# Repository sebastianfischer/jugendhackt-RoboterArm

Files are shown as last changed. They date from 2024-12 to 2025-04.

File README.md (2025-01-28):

# RoboterArm

Design, Idee und Umsetzung: @dgreiser 

# Was machen wir?
## Step 1: Zusammenbauen
Du baust aus Servomotoren, Gelenken und einem Greifer einen funktionierenden Roboterarm. Keine Sorge, wir erklären alles Schritt für Schritt.

## Step 2: Programmieren
Mit einem Microcontroller (z. B. einem Raspberry Pi Pico) programmierst du, wie der Roboterarm sich bewegen soll. Ob er Sachen greifen, sich drehen oder coole Bewegungen ausführen soll – du steuerst ihn komplett!

# Für wen ist der Workshop?
Für alle zwischen 12 und 18 Jahren, die Lust haben, mit Technik zu experimentieren. Vorkenntnisse? Nicht nötig! Neugier reicht.

# Warum solltest du mitmachen?
- Du lernst, wie Roboter wirklich funktionieren.
- Du tauchst in die Welt der Programmierung ein – ohne langweilige Theorie.
- Du kannst am Ende stolz deinen eigenen Roboterarm präsentieren.
- Es macht einfach mega Spaß, mit anderen zu bauen und zu coden!

# Was brauchst du?
Nichts außer Motivation! Wir stellen alles zur Verfügung, was du für den Workshop brauchst.

See the robot arm in aktion (https://www.youtube.com/watch?v=oafrhNWhoxY)

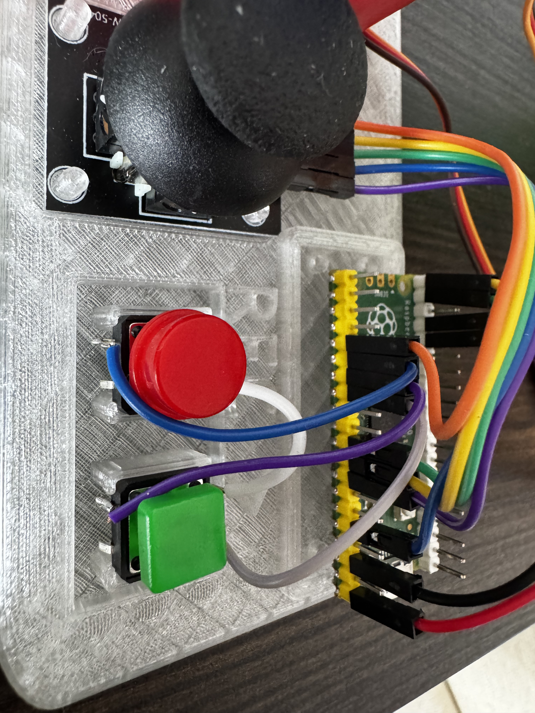
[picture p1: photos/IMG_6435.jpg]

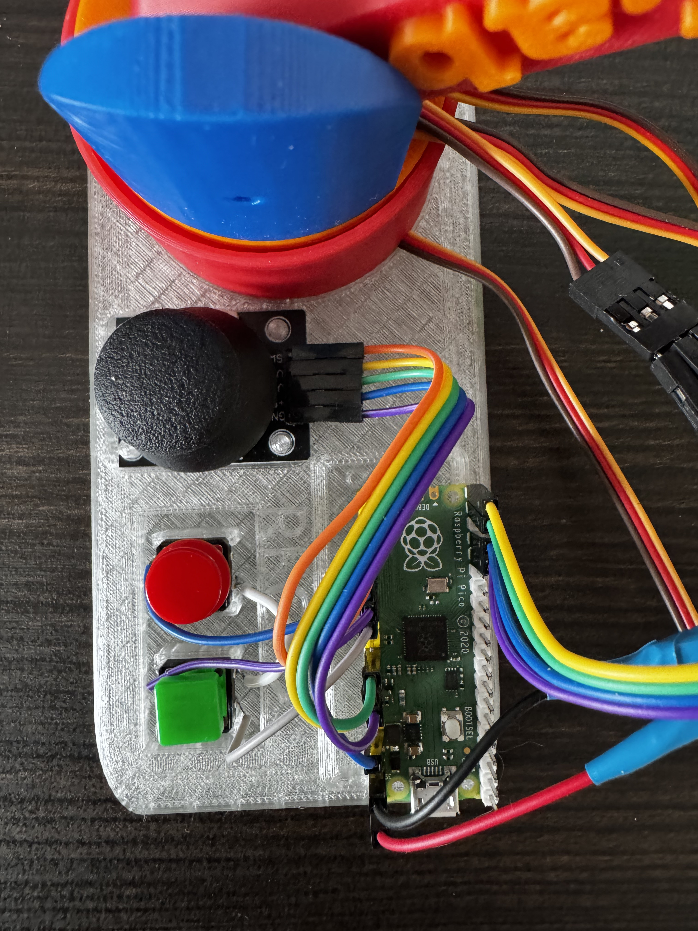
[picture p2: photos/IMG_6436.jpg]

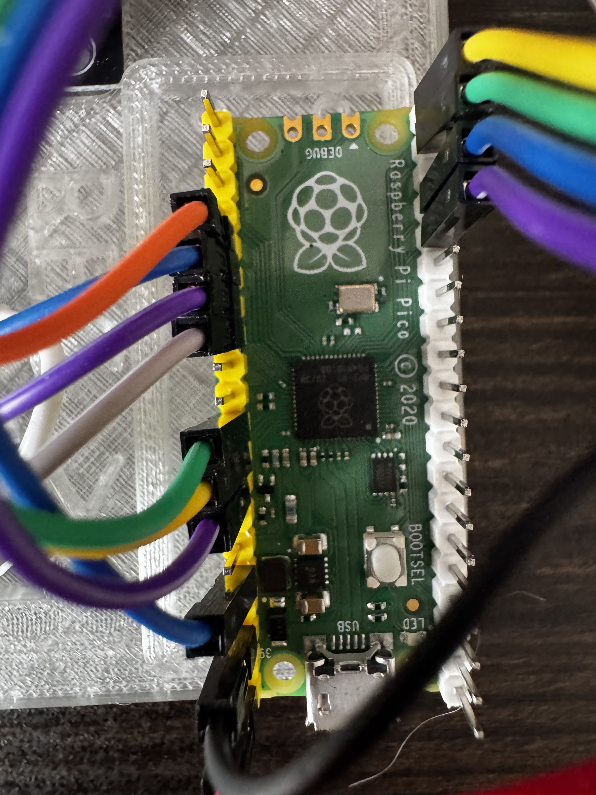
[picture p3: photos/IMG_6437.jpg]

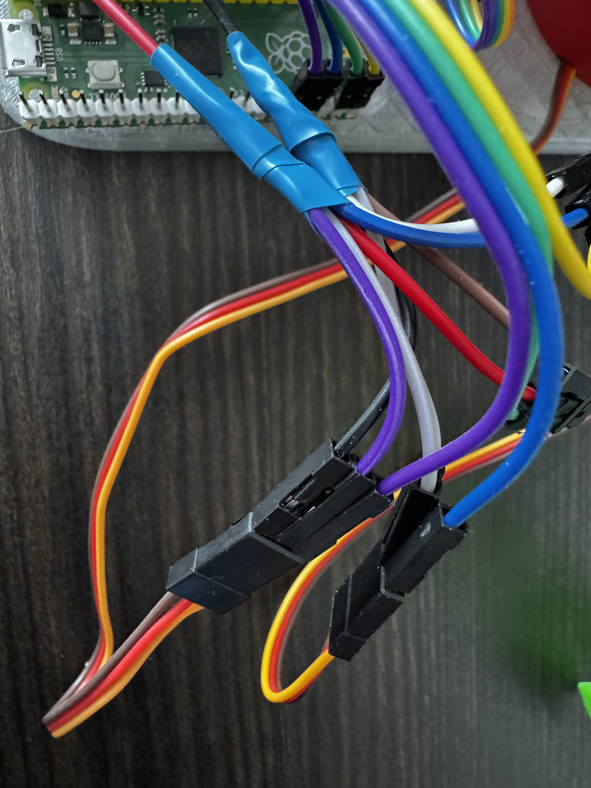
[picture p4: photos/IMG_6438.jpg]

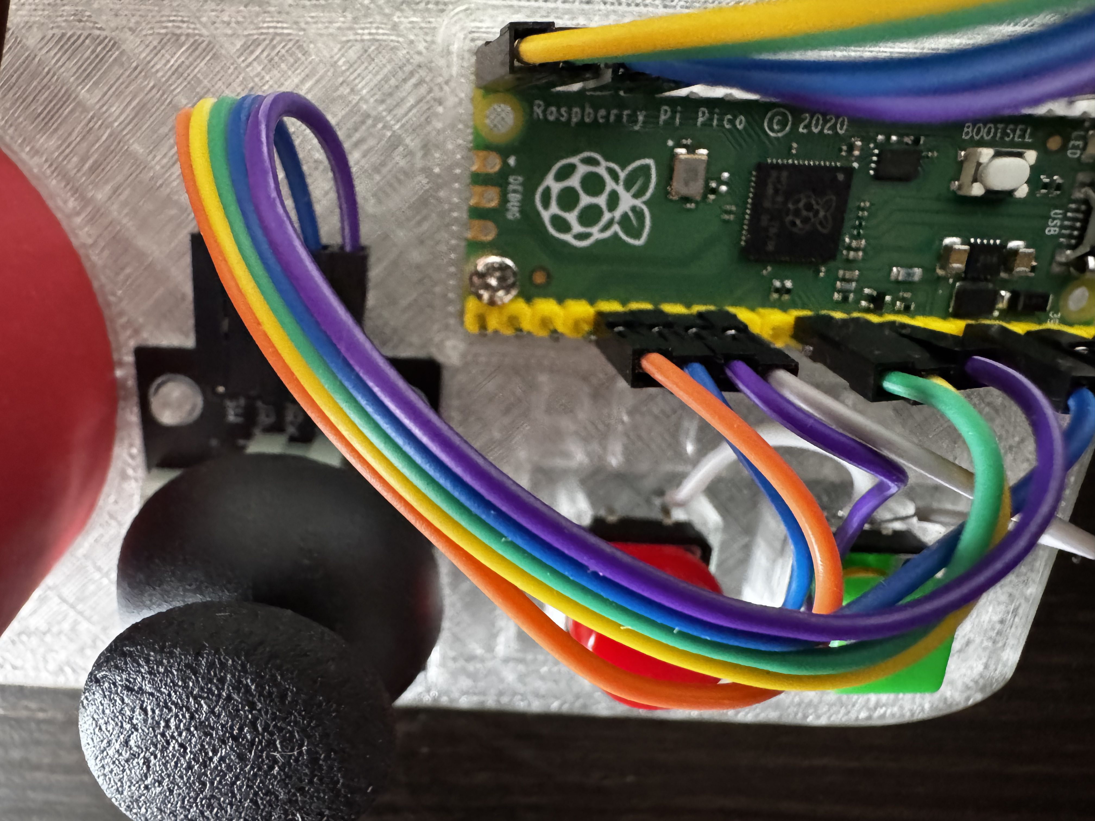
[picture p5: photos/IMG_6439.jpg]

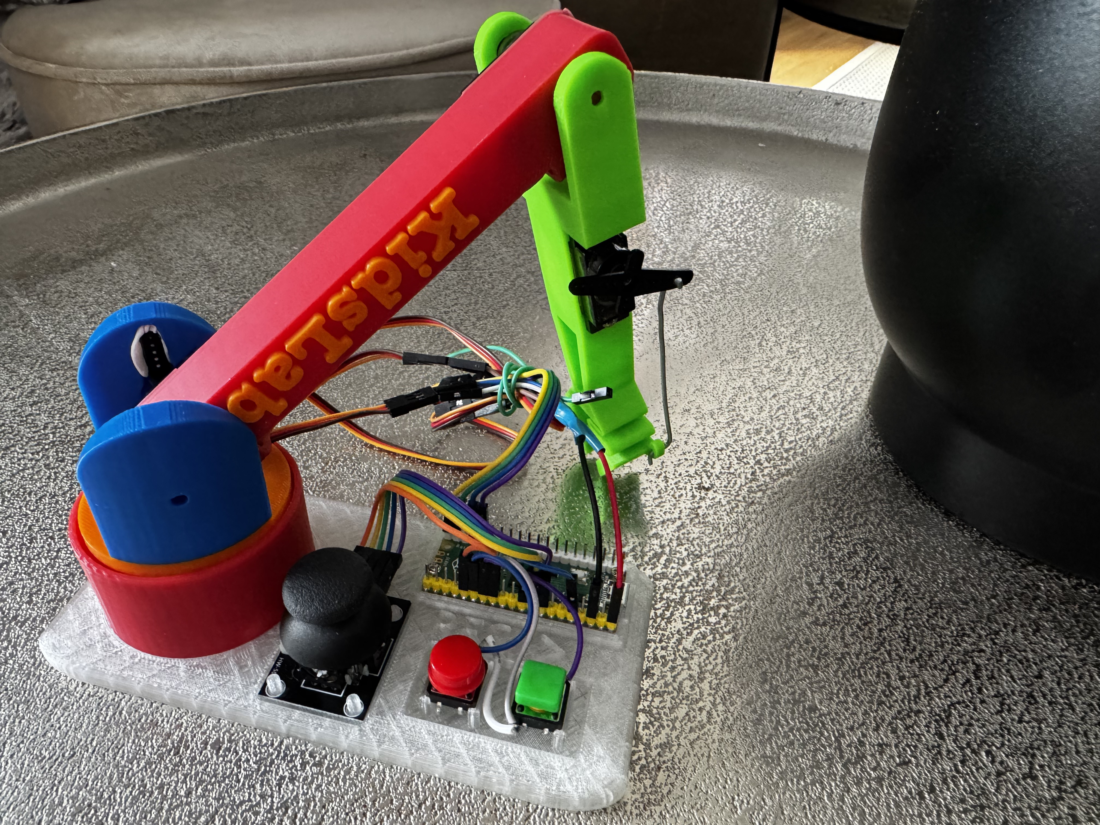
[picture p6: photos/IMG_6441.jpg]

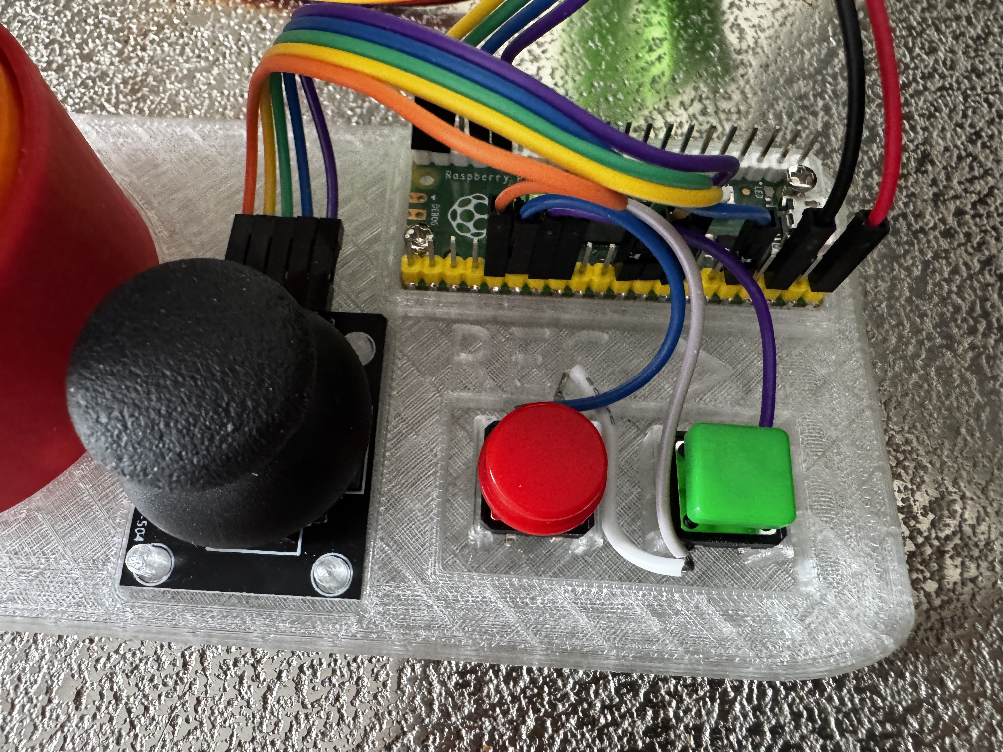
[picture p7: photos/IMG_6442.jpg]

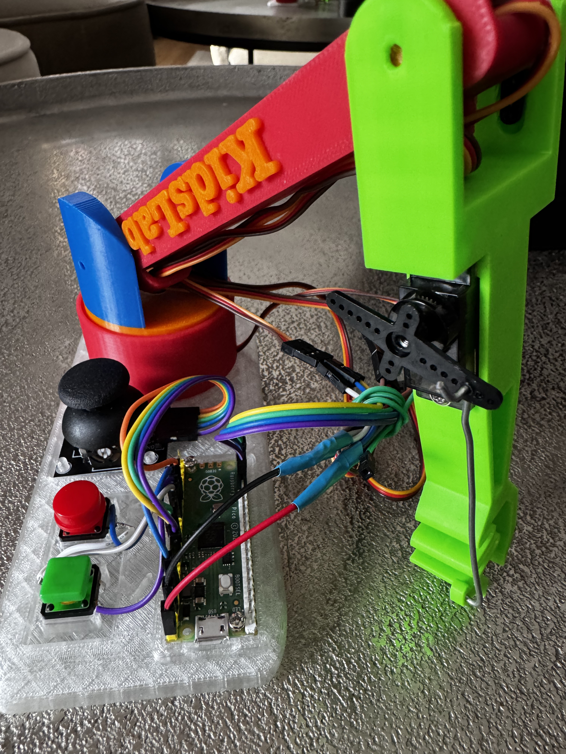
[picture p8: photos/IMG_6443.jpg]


# Teileliste - für den Nachbau zuhause

4x Servos - standard 9g - am besten mit Metalgetriebe
1x Raspberry Pico - oder anderen mit CircuitPython-Unterstützung
1x Joysticj
1x eine Handvoll Kabel 
2x Knöpfe deiner Wahl - zum Beispiel diese hier

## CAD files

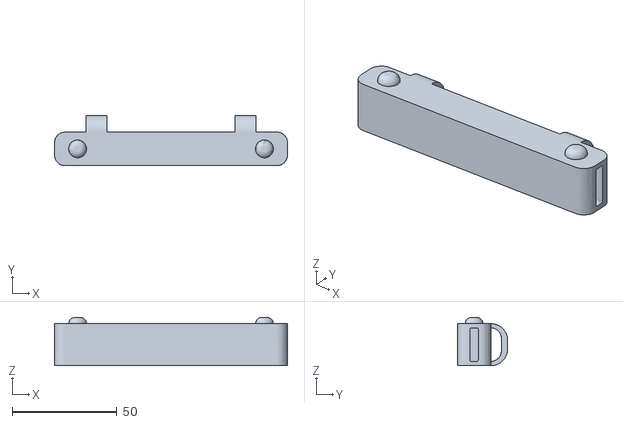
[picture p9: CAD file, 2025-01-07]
stl/arm_kurz.stl
111.0 x 24.0 x 23.0

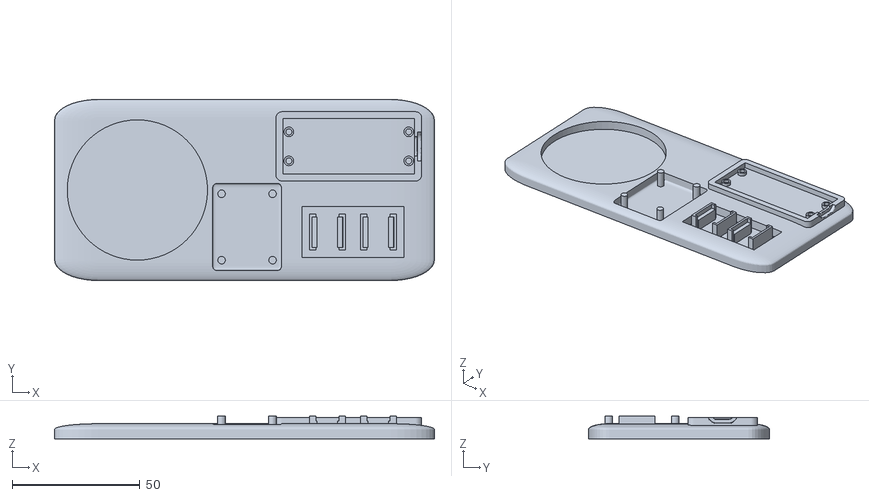
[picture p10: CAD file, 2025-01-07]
stl/Roboter Base.stl
149.0 x 71.0 x 9.00

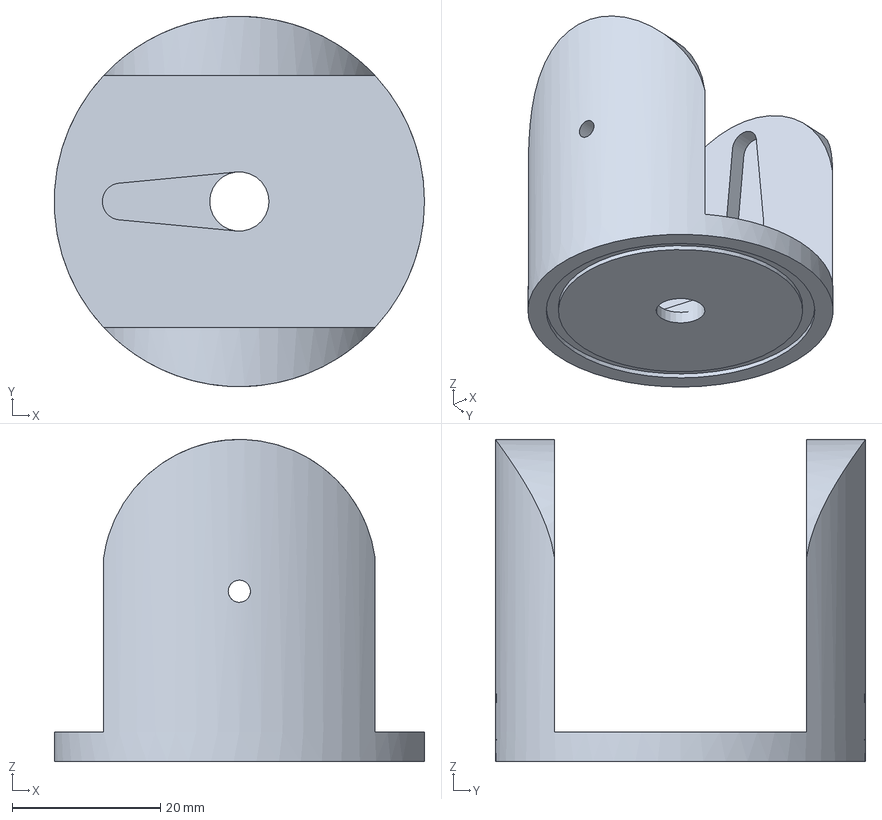
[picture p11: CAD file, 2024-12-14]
stl/turning-base.3mf
50.0 x 50.0 x 43.5 mm

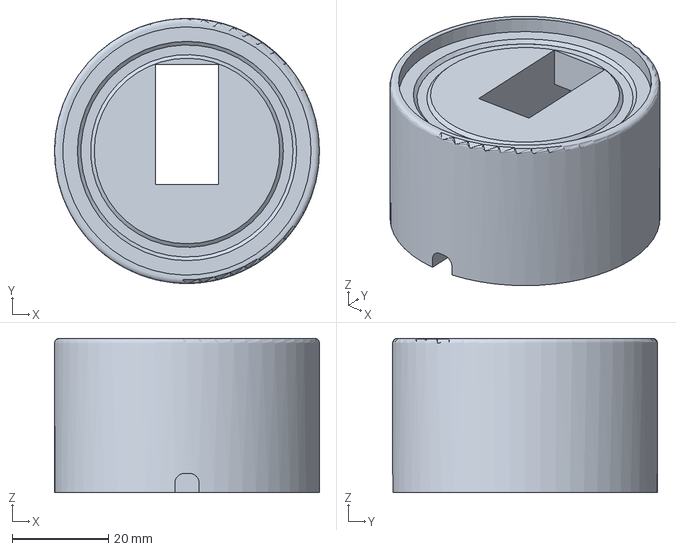
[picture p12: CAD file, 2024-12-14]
stl/base.3mf
55.0 x 55.0 x 32.0 mm

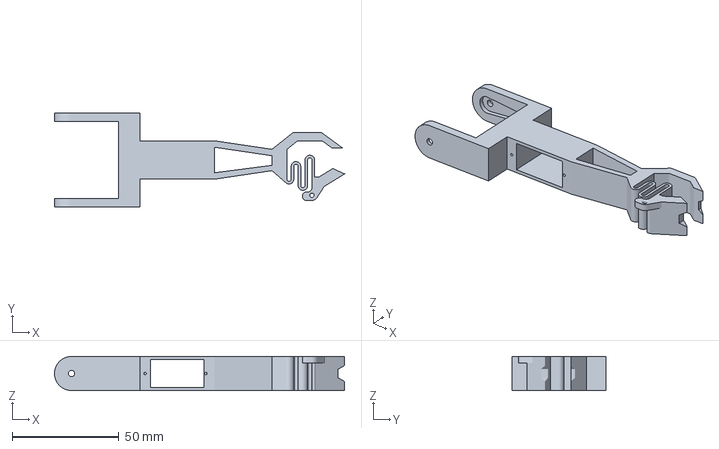
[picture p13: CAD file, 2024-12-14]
stl/Gripper.3mf
136.0 x 44.0 x 16.0 mm

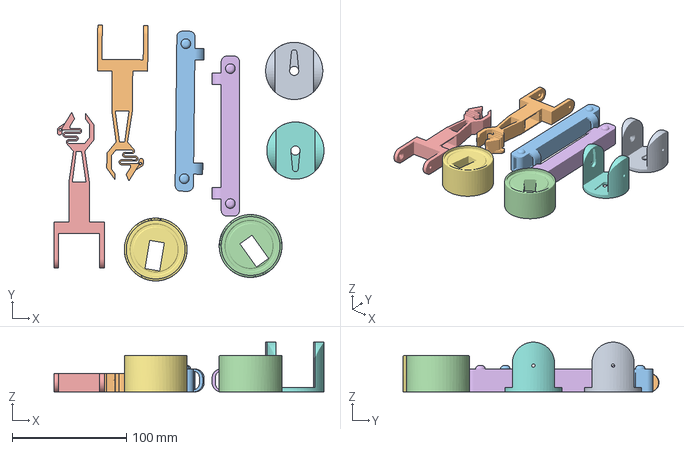
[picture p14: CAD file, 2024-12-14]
stl/Roboter-komplett-2x.3mf
236.1 x 223.8 x 43.5 mm
Gripper.stl x 2

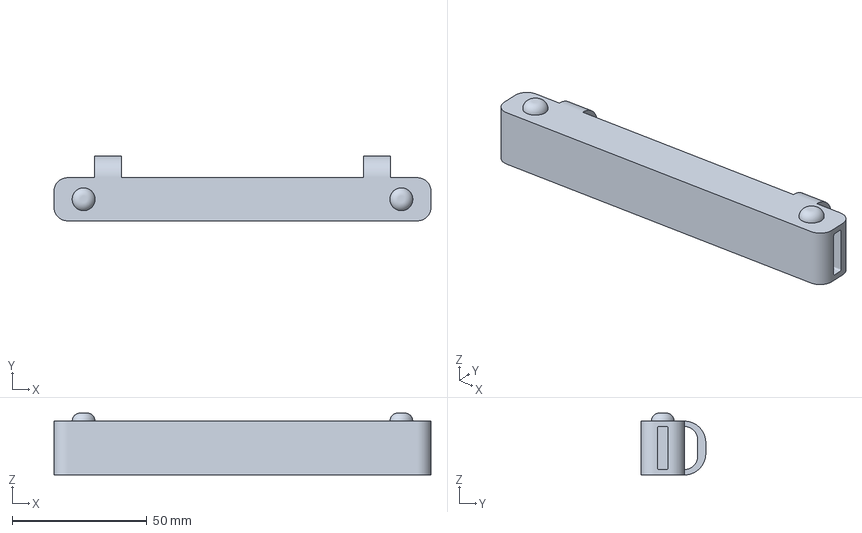
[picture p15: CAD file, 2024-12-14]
stl/arm.3mf
140.0 x 24.0 x 23.0 mm

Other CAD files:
stl/Gripper.stl
stl/arm.stl

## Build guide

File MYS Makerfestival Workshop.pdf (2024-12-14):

# Baut und

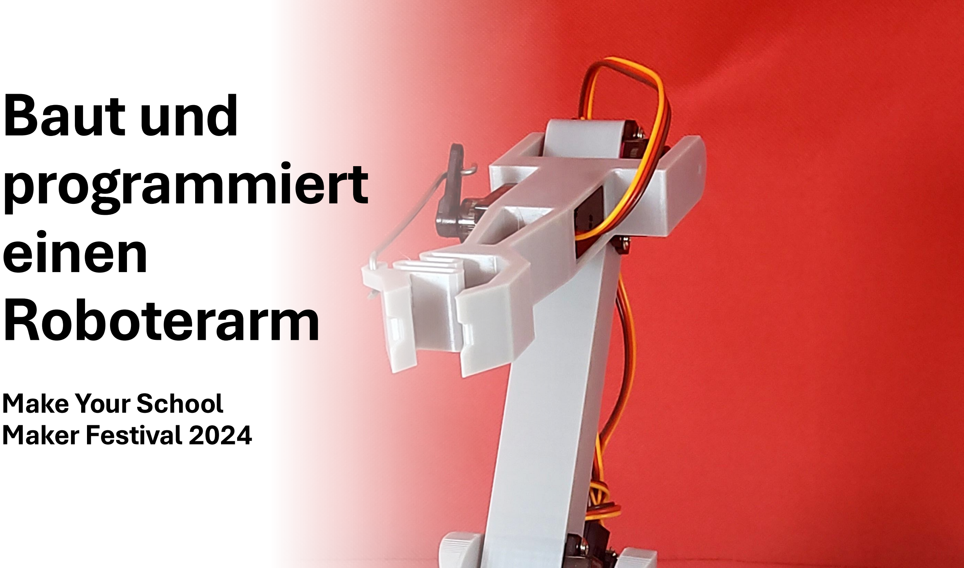
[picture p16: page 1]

# programmiert einen Roboterarm

### Make Your School Maker Festival 2024

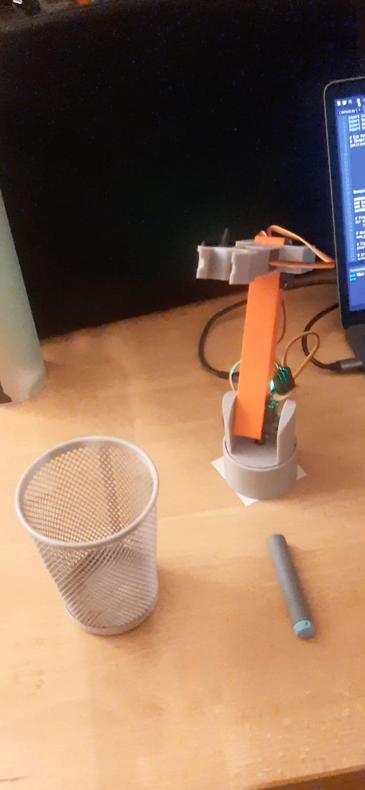
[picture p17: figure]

# Unser Ziel!

# Servos!

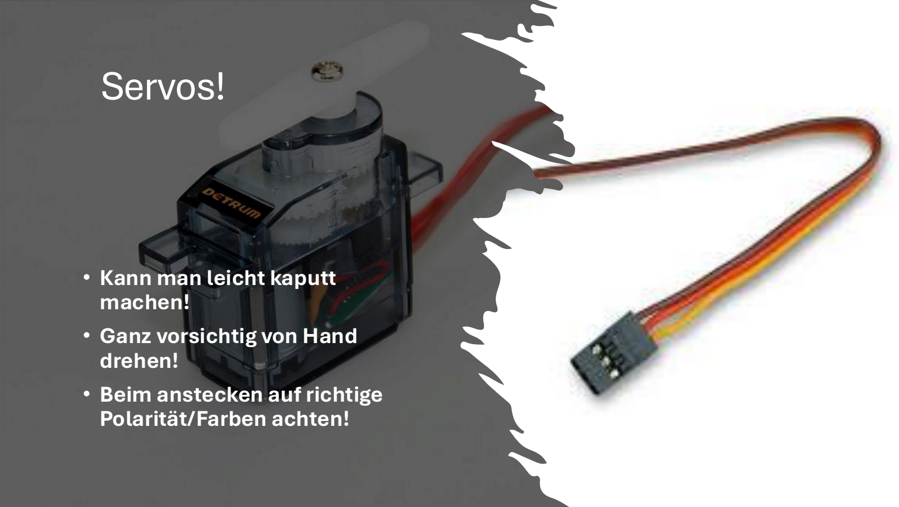
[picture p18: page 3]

- Kann man leicht kaputt
machen!
- Ganz vorsichtig von Hand drehen!
- Beim anstecken auf richtige Polarität/Farben achten!

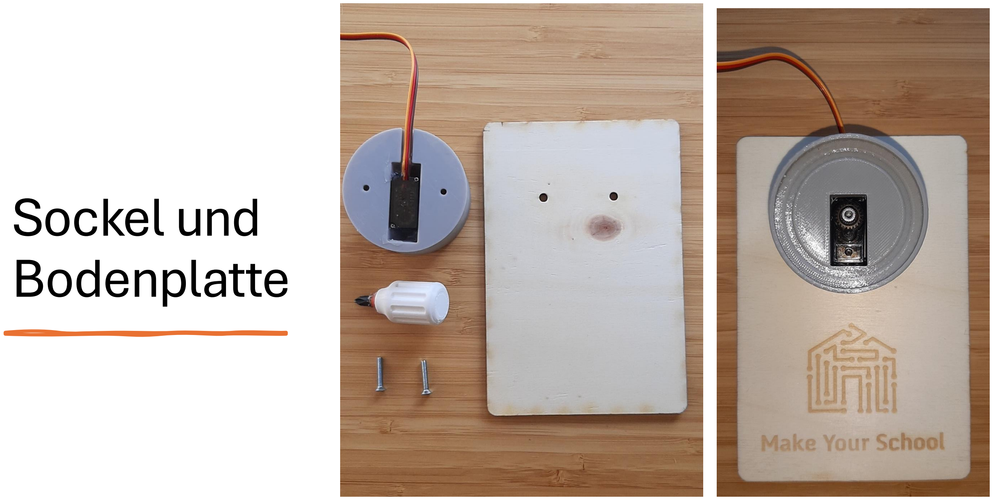
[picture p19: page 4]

# Sockel und Bodenplatte

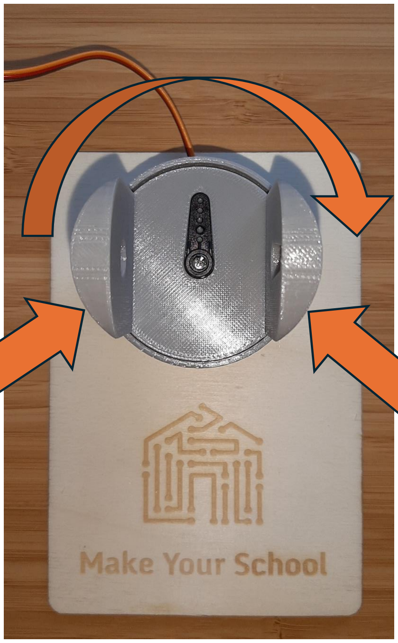
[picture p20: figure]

# Drehgelenk

Auf Ausrichtung des
Servos achten!

Der schwarze Servoarm
sollte etwa auf die Pfeile zeigen wenn du das
Drehgelenk drehst.

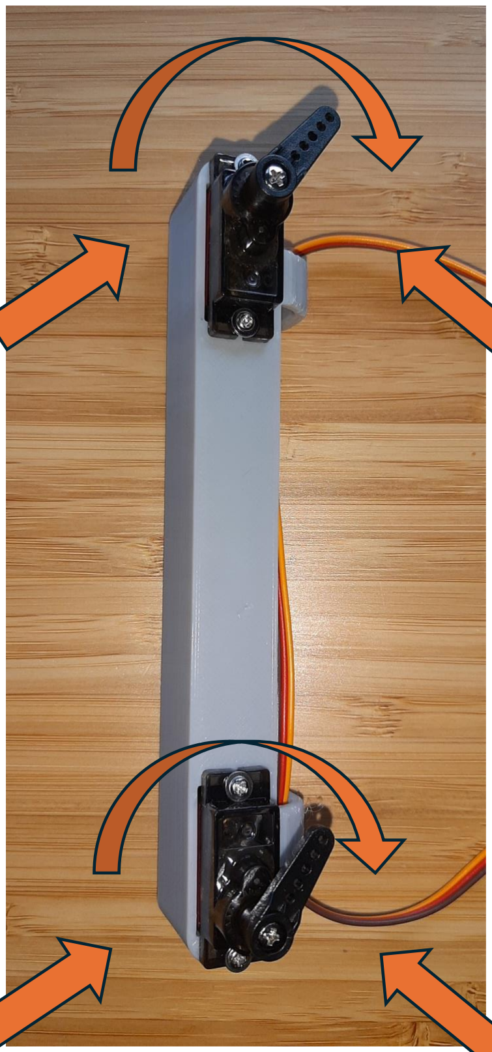
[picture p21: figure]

# Gelenkarm

Die Kabel von innen durch den Spalt nach außen stecken
Beide Servos schauen mit dem Zahnrad nach außen.

Servohörner wieder so anbringen dass diese sich vorsichtig bis zu den Pfeilen bewegen lassen.

Beide Servohörner zeigen in die gleiche Richtung

## Gestänge für den Greifer 1/2

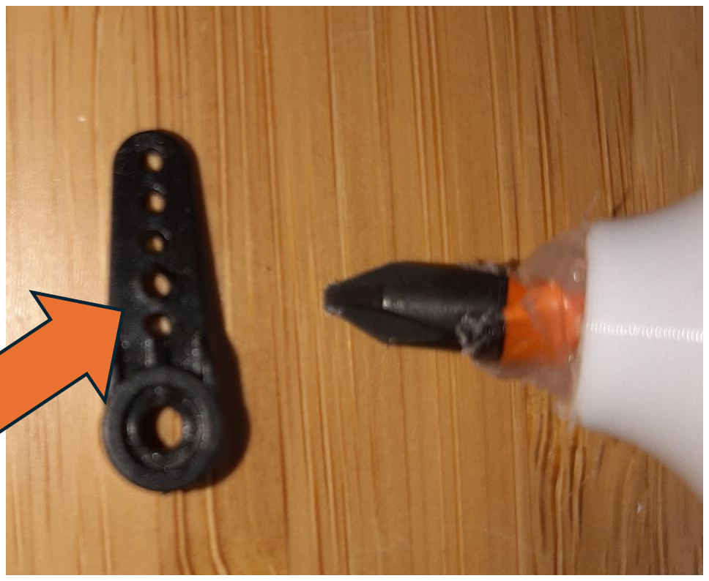
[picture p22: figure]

Mit dem Werkzeug eines der

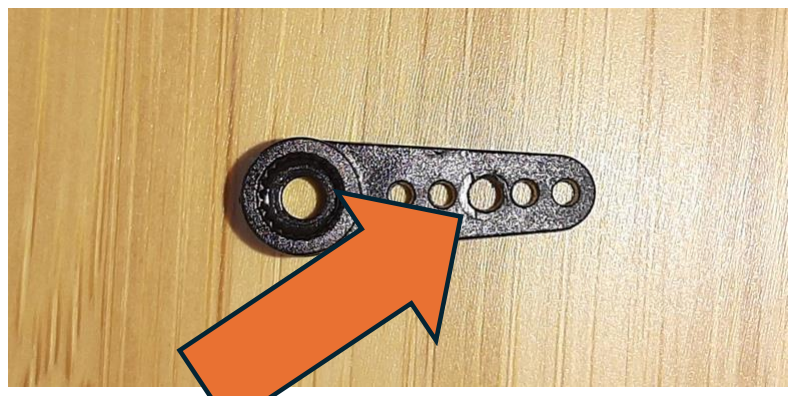
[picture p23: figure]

mittleren Löcher größer machen

## Gestänge für den Greifer 2/2

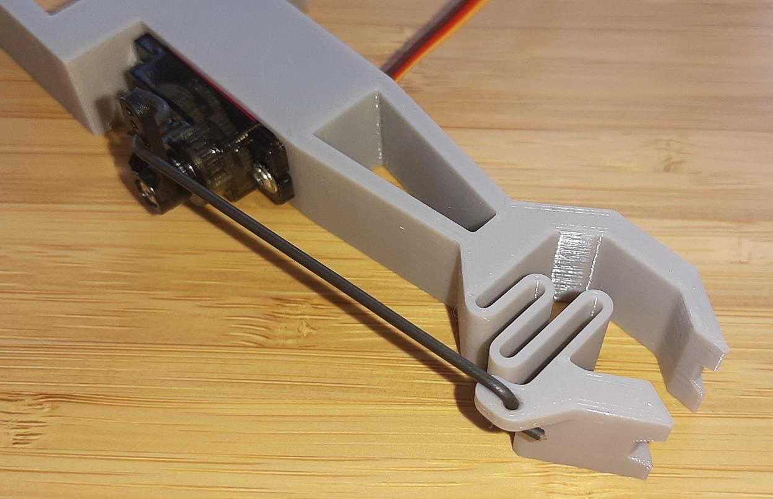
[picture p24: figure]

Vorsicht beim Einfädeln in den Greifer, die Öse bricht leicht ab!

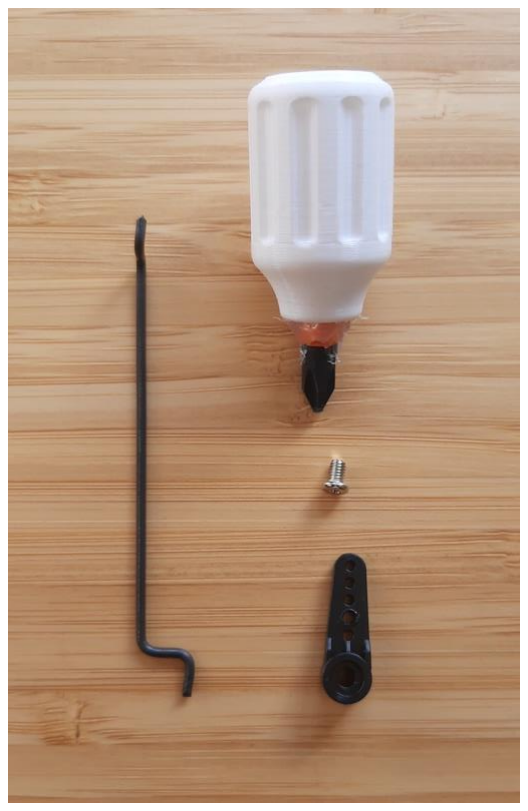
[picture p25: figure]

# Zusammenbauen und Kabelmanagement

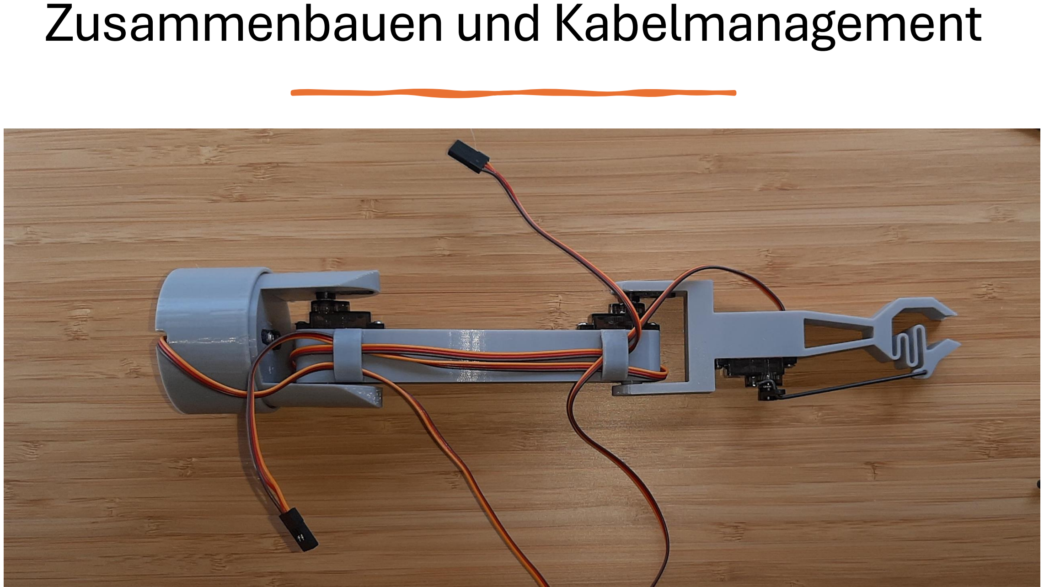
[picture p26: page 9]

# Zusammenbauen und Kabelmanagement

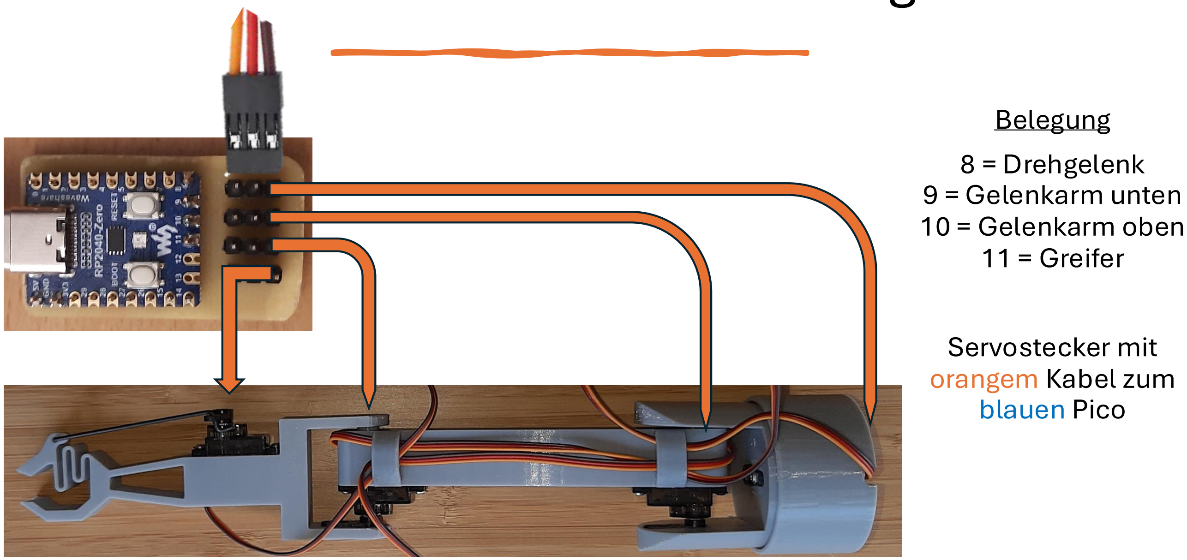
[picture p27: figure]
Belegung 8 = Drehgelenk 9 = Gelenkarm unten 10 = Gelenkarm oben 11 = Greifer; Servostecker mit orangem Kabel zum blauen Pico

# Checkliste!

### ☐ Sockel an Bodenplatte geschraubt? ☐ Alle Servos können sich frei in beide Richtungen bewegen? ☐ Die Metallstange am Greifer und Servo montiert? ☐ Alle Servokabel stecken mit dem orangen Kabel Richtung Pico?

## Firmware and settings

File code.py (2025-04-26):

import board
import analogio
import time
import pwmio
from adafruit_motor import servo
import digitalio


def init():
    global positionen, position, DEBUG, Bewegungsdauer, last_position, x_axis, y_axis, achsen, pwm1, pwm2, pwm3, pwm4, servo1, servo2, servo3, servo4, pwms, btn_rec, btn_change, axis_12, btn_play, GradProKlick
    last_position = 90
    position = 90
    positionen = [[90, 90, 90, 90]]

    DEBUG = True
    Bewegungsdauer = 0.4
    GradProKlick = 5

    x_axis = analogio.AnalogIn(board.GP26)
    y_axis = analogio.AnalogIn(board.GP27)

    achsen = [90, 90, 90, 90]
    pwm1 = pwmio.PWMOut(board.GP12, duty_cycle=0, frequency=50)
    pwm2 = pwmio.PWMOut(board.GP13, duty_cycle=0, frequency=50)
    pwm3 = pwmio.PWMOut(board.GP14, duty_cycle=0, frequency=50)
    pwm4 = pwmio.PWMOut(board.GP15, duty_cycle=0, frequency=50)

    servo1 = servo.Servo(pwm1, min_pulse=500, max_pulse=2250)
    servo2 = servo.Servo(pwm2, min_pulse=500, max_pulse=2250)
    servo3 = servo.Servo(pwm3, min_pulse=500, max_pulse=2250)
    servo4 = servo.Servo(pwm4, min_pulse=500, max_pulse=2250)

    pwms = [pwm1, pwm2, pwm3, pwm4]

    btn_rec = digitalio.DigitalInOut(board.GP20)
    btn_rec.direction = digitalio.Direction.INPUT
    btn_rec.pull = digitalio.Pull.UP

    btn_play = digitalio.DigitalInOut(board.GP21)
    btn_play.direction = digitalio.Direction.INPUT
    btn_play.pull = digitalio.Pull.UP

    btn_change = digitalio.DigitalInOut(board.GP19)
    btn_change.direction = digitalio.Direction.INPUT
    btn_change.pull = digitalio.Pull.UP

    axis_12 = True


init()


def get_voltage(pin):
    return (pin.value * 3.3) / 65536


def ease_in_out(t):
    if t < 0.5:
        return 4 * t * t * t
    else:
        p = 2 * t - 2
        return 0.5 * p * p * p + 1


def move_servos_eased(servos, start_positions, end_positions, duration):
    steps = 500
    for i in range(steps + 1):
        t = i / steps
        eased_t = t * t * (3 - 2 * t)
        for servo, start_pos, end_pos in zip(servos, start_positions, end_positions):
            if DEBUG:
                print("Servo: ", servo, "Start: ", start_pos, "End: ", end_pos)
            servo.angle = start_pos + (end_pos - start_pos) * eased_t
        time.sleep(duration / steps)


servo1.angle = achsen[0]
servo2.angle = achsen[1]
servo3.angle = achsen[2]
servo4.angle = achsen[3]

while True:
    x_val = get_voltage(x_axis)
    y_val = get_voltage(y_axis)

    if last_position is None or position != last_position:
        print(position)
        if position > (90 / GradProKlick):
            position = (90 / GradProKlick)

        if position < -(90 / GradProKlick):
            position = -(90 / GradProKlick)

        winkel = 90 + position * 5
        servo1.angle = winkel
    last_position = position

    time.sleep(0.1)


    if axis_12:
        axis1 = 1
        axis2 = 2
    else:
        axis1 = 0
        axis2 = 3
        
    if y_val > 1.75 or y_val < 1.55:
        achsen[axis1] = max(0, min(180, achsen[axis1] + int((y_val - 1.65))*5))
        direction = "rechts" if y_val < 1.6 else "links"
        if axis_12:
            servo2.angle = achsen[axis1]
        else:
            servo1.angle = achsen[axis1]
       # print(f"Joystick nach links {axis1} {achsen[axis1]}")
        print(f"Joystick nach {direction} {axis1} {achsen[axis1]} ({y_val})")

        
    if x_val > 1.75 or x_val < 1.55:
        achsen[axis2] = max(0, min(180, achsen[axis2] + int((x_val - 1.65))*5))
        direction = "oben" if x_val < 1.6 else "unten"
        if axis_12:
            servo3.angle = achsen[axis2]
        else:
            servo4.angle = achsen[axis2]
        print(f"Joystick nach {direction} {axis2} {achsen[axis2]} ({x_val})")

    if not btn_play.value:
        print("PLAY is pressed")
        for i in range(len(positionen)):
            print(positionen[i])
            move_servos_eased([servo1, servo2, servo3, servo4], achsen, positionen[i], Bewegungsdauer)
            achsen = positionen[i]
        print("Ende")

        time.sleep(1)
    if not btn_rec.value:
        print("REC is pressed")
        if positionen[-1] != achsen:
            positionen.append(achsen.copy())
            print("Position hinzugefügt")
        else:
            print("Position schon vorhanden")
        print(positionen)
        time.sleep(1)

    if not btn_change.value:
        print("CHANGE is pressed")
        axis_12 = not axis_12
        print(axis_12)
        time.sleep(1)

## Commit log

2024-12-14 Daniels version vom Maker Festival
    [Gripper.3mf, Gripper.stl, Roboter-komplett-2x.3mf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]
2025-01-07 photos, stl für die base und guuuuuter code
    [Roboter Base.stl]
2025-01-07 kurze vesion des arms
    [arm.stl, arm_kurz.stl]
